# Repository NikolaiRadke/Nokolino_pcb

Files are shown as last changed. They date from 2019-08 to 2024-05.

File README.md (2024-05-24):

Nokolino  

The ATtiny-based litte brother of Noko. Tiny and cute. And everyone is invited to **contribute**. Nokolino is for everyone. This repository is for the **PCB** version of Nokolino, easy and fast to build. See [PCB](https://github.com/NikolaiRadke/NOKOlino_2/tree/master/PCB.md) on how to get your own boards. Do you own a complete kit? Look [here](https://github.com/NikolaiRadke/Nokolino).    
  
What's new? See the [newsblog](https://github.com/NikolaiRadke/NOKOlino_2/tree/master/NEWS.md).   

Three NOKOlinos
  
Like his big brother **Noko**, the little Nokolino delights it's surroundings with cheeky comments. But unlike Noko he is more obstinate - no radio, a display, no frills. Instead of an Arduino he has a small **ATtiny** microcontroller, only an on-off switch and a big button. But he is small, can stay active for days and is, in contrast to his big brother, very easy to build.  
  
Another useful application option would be to use the hardware without the monster suit as a **music box** in an old used doll to bring it back to modern days, maybe with other sounds or songs.  

What does he to - technically? Whenever you press his button, he will laugh. And when he's just turned on, he says something random randomly every statistically 10 minutes. That's ist. Quiet a lot for a stuffed monster!  
  
**Nokolino** stands for **No**ra and Ni**ko**s monster - the appendix **lino** describes the small version.  
  
### Notes for non-German Nokolino makers  
  
Right now, the building wiki, the voice set and the manual are in German. I'll try to translate the wiki and the manual one day. Until then, feel free to ask me for translation, if you need help. **Contribute!** I need an English voice set and English text files. In addition, any other language is welcome, Nokolino is to be cosmopolitan!
  
### Prerequisites
  
Nokolino needs Arduino IDE 1.6.6 or newer (https://www.arduino.cc/en/Main/Software). Copy the folder `Nokolino/src/Nokolino_V30/` for the **JQ6500** module, `Nokolino/src//Nokolino_V31/` for the **JQ8400** module, `Nokolino/src/Nokolino_V32/`for the **DFPlayer** module or `Nokolino/src/Nokolino_V21/` for **older 2018 kits** into your sketch folder and install ATtiny support. See [how to compile](https://github.com/NikolaiRadke/Nokolino_pcb/tree/master/howto_compile) for further instructions. 
  
### Content

```
Nokolino/
├── howto_compile/
|   Manual how compile the sketches in your Arduino IDE.
|
├── linux_uploader/
|   Tool for uploading MP3-files to the JQ6500.
|
├── manual/
|   Nokolino manuals in PDF format.
|
├── mp3/
|   Voice sets for 32MBit- & 16MBit modules in German. English needed? Contribute!
|   ├── Nokolino/
|   |   Male voice sets, spoken by Carsten Caniglia.
|   |   ├── 2MB/
|   |   |   80 files for smaller (16 MBit) modules.
|   |   └── 4MB/
|   |       164 files for recommended (32 MBit) modules.
|   └── Nokolina/
|       Female voice set, spoken by Norma Anthes
|       ├── 2MB/
|       |   80 files for smaller (16 MBit) modules.
|       └── 4MB/
|           164 files for recommended (32 MBit) modules.
|
├── schematics/
|   The circuit diagrams, 3D cab model and sewing pattern.  
|   └── gerber/
|       The gerber files for the PCB to build by your own.
|       ├── V30/
|       |   The gerbers for the JQ6500 module.
|       ├── V31/
|       |   The gerbers for the JQ8400 module.
|       └── V32/
|           The gerbers for the DFPlayer module.
|
└── src/
    ATtiny sketches
    ├── Nokolino_V21/
    |   Old software for old 2018 kits.
    ├── Nokolino_V30/
    |   The sketch for the JQ6500 module.
    ├── Nokolino_V31/
    |   The sketch for the JQ8400 module.
    └── Nokolino_V32/
        The sketch for the DFPlayer module.
```
### Let's get started!

Interested in Nokolino? Great! Let's start here: [German wiki](https://github.com/NikolaiRadke/Nokolino_pcb/wiki).  
English wiki will follow. One day...

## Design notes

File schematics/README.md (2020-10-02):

# Schematics

* **Nokolino_V32.pdf** Nokolnio's circuit diagram for the DFPlayer module.
* **Nokolino_V31.pdf** Nokolino's circuit diagram for the JQ8400 module.  
* **Nokolino_V30.pdf** Nokolino's circuit diagram for the JQ6500 module.  
* **M2_button_cab.stl** The 3D model for the button cabs for self printing.  
* **Nokolino_Pattern.pdf** Nokolino's sewing pattern.  
* **/gerber**  The folder for the gerber files needed to print your own PCBs.

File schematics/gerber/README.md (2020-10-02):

# Gerber files  
  
Here you find the folders for the gerber files to print the PCBs by a manufactor of your choice. 

**V3.2** is for the DFPlayer module.  
**V3.1** is for the JQ8400 module.  
**V3.0** is for the JQ6500 module.

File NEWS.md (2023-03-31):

# Newsblog
  
# 2023  
* **31.03.2023** Added a deep sleep mode for V3.2. If you forget to turn him off, he will draw only 6,5mAh insted of 16,5mAh.  
* **18.03.2023** Fixed a bug that prevented resetting the battery low flag. Updated all Firmwares to **X.X-180323**. 
* **11.01.2023** Finally i found out that not all DFPlayer devices support USB. Luckilyy new Version 220920 of the MH2024K-24SS chipset solves this nasty issue.  
  
# 2022
* **30.01.2022** Started german wiki integration of the new V3.2 version. Hopefully the last (and best) version for a longer time...  
* **27.01.2022** Firmware **3.2-270122**: All DFPlayer modules are supported now. Battery warning is working reliable and the music box mode can now skip to the next track by pressing the button for 3 seconds. Ready to release.  

# 2021
  
* **17.01.2020** Happy new year" Stay tuned for a complete V3.2 wiki integration.  

# 2020  
  
* **30.09.2020** Firmware **3.2-300920** and V3.2 schematics are online.  
* **29.09.2020** Good news: A new Version **V3.2** with the **DFPlayer** MP3 module for microSD cards is available! Nokolino can be used as a speech set monster and, by pressing the button on startup, as a music box for tons of files, uploadable via USB.  
* **28.08.2020** All Boards are getting a slight rework with JST plugs an cables for easier assembly.
* **10.07.2020** Tested new IDE 1.8.13. Works good.  
* **27.06.2020** Added software support for old V2.1 kits.  
* **25.06.2020** New firmware **3.1-250620**: Music box mode now plays more than one file. 3.0 will follow soon.     
* **23.06.2020** The kit and the workshop ticket are now availabe at [heise shop!](https://maker-faire.de/workshops/bauset-workshops/) Cheers!  
* **12.06.2020** Linked [PCB.md](https://github.com/NikolaiRadke/Nokolino_pcb/blob/master/PCB.md) to my [Aisler](https://aisler.net/Monstermaker) repository for easy pcb ordering.  
* **10.06.2020** A kit is available! Look [here](https://maker-faire.de/workshops/bauset-workshops/).  
* **06.06.2020** New release **V3.0-180520**.  
* **04.06.2020** Updated to firmware **3.0-180520** and **3.1-180520**. Only cleanup changes made.    
* **03.06.2020** Started reworking this repository and the wiki.  
* **02.06.2020** The Nokolino kit and the new repository are ready!    
* **26.03.2020** Finally, i found the last missing part for the new Nokolino kit: A solderless USB plug! The wiki will be updated very soon.   
* **22.03.2020** The V3.1 boards for the JQ8400 modules are working.  
* **09.03.2020** New PCBs arrived! The top board fits perfectly to the new designed M2 screw button caps. The V3.1 with alternative JQ8400 module will be tested soon.  
* **08.03.2020** Tested IDE 1.8.12. Yeah, working.  
* **14.02.2020** Nokolino doesn't need glue anymore! You can 3D print your own M2 button caps and connect the new upper PCB with the four buttons by a M2 6mm screw. Surely, old glue cabs are still working.      
* **13.02.2020** Testet IDE 1.8.11. Again, it's working.  
* **11.02.2020**:
  * New firmware **3.1-110220**: Optimized operating voltage range for new JQ8400.  
  * New firmware **3.0-110220**: Reduced flash size and fixed missing optional startup beep.  
* **10.02.2020** Good news: Bigger JQ6500 modules with 32MBit are getting rare. I made an alternative Version V3.1 for the cheap and easy to buy **JQ8400-10p** module with 32MBit too. The software is working and the new PCBs are ordered. Stay tuned!
* **24.01.2020** New V3.0 PCBs are working great. New instructions and the new German wiki will follow next month.  
* **03.01.2020** New firmware **3.0-030120**. Autodetecting playmode and reduced flash size. Remember, this version will only run on coming PCBs.  
* **01.01.2020** Happy new year! The new V3.0 PCB-files are online. The wiki will be updated after testing was done.  

# 2019
  
* **30.12.2019** New Nokolino V3.0 is comming early next year!   
* **26.09.2019** Tested IDE 1.8.10. Still working.  
* **27.08.2019** New linux upload and repair tool. The make command now works with Debian/Ubuntu/Mint.  
* **05.08.2019** New release **V2.1-030819**.  
* **03.08.2019** Firmware **2.1-030819**: With some small hardware additions Nokolino can get a new voice set via USB!  
* **16.06.2019** Firmware **2.0-160419**: Fixed a bug for the optional dark mode.  
* **14.04.2019** Testet IDE 1.8.9. Works too.  
* **15.01.2019** Firmware **2.0-150119**: Reworked volume control. Some modules have issues after sleep mode.  
* **15.01.2019** Testet IDE 1.8.8. Works well.  

## 2018

* **19.10.2018** New Linux upload tool. You can upload an english interface by typing ./jq6500 -X   
* **26.09.2018** See Nokolino and me at Wissensnacht Ruhr Gelsenkirchen: 28.08.2018.  
* **25.09.2018** Firmware **2.0-250918**: Optional complaining when button is pressed while it is dark.
* **22.09.2018** Firmware **2.0-220918**:
  * Optional startup beep.  
  * Optional phototransistor feature.  
  * Improved volume handling, some modules need more startup time.  
* **07.09.2018** New Nokolino with QI wireless charging module and internal power button is ready! Works great!  
* **05.09.2018** Updated PCB design:
  * More room for a USB cable for your JQ6500.    
  * Opportunity to add the new phototransistor feature.  
* **03.09.2018** See Nokolino an me at the Maker Faire Hannover: 15.09.-16.09. HCC Hannover.  
* **31.08.2018** Firmware **1.0-310818**: Optimized PCB battery warning settings.  
* **29.06.2018** Firmware **1.0-290618**: Improved power saving when battery is low.  
* **16.06.2018** Updated the upload tool.  
* **24.05.2018** Firmware **1.0-240518**: New 16MBit voiceset support.  
* **23.05.2018** Better data compression for 16MBit voiceset. You get 10 more files!  
* **22.05.2018** Added 16Mbit module support.  
* **15.05.2018** Updated the upload tool for the JQ6500 mp3 module. Note that it now needs the **-W** parameter to write files.  
* **14.05.2018** See Noko and me at the Maker Faire 2018 in Berlin: 25.10.2018-28.10.2018, FEZ!  
* **12.05.2018** The new repository for PCB Nokolino is ready! Go on, Nokolino lovers!

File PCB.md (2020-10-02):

# PCB - How to get your own NOKOlino boards

**30.09.2020**  

Nokolino_pcb is made of **two** boards. Both of them are 6x5 cm, with two layers: The **main board** for the buttons, 
the charging module, the ATtiny and the MP3 module, the **top board** for the speaker. The battery is on the 
downside of the main board.  

There are three versions: **V3.0** for the **JQ6500-16p** MP3 module, **V3.1** for the **JQ8400-10p** MP3 module and **V3.2** for the **DFPlayer**. I recommend using the newer JQ8400, if you just need a monster. Do you want Nokolino to play longer files like musc then choose the DFPlayer.  
  
There are **three** ways to get your own set of boards:

1. Upload the chosen [gerber files](https://github.com/NikolaiRadke/Nokolino_pcb/tree/master/schematics/gerber) to a PCB manufactor of your choice. In China, you can order a set of 10 boards for about 15€ in less then three weeks. If you are in a hurry, you can choose express shipping. But be careful: in Germany, if your order has a value more than 22€ including shipping costs, you have to pay taxes and a processing fee, which also takes additional time! So try to keep your or order **below 22€**! if you need help, feel free to contact me. Order specifications: two layers and standard presets like PCB thickness 1.6. In Germany, i recommend [Aisler](https://aisler.net/Monstermaker), were you get three PCBs for less then 19€, including shipment. With the top PCB, 38€ for three Nokolinos within three days. Fair.    
 
2. There will be a complete kit available in the heise store. Look at the [kit repository](https://github.com/NikolaiRadke/Nokolino) and stay tuned!  
  
3. Contact me. I have always some boards and sometimes a few kits left. But please: First try to order them by yourself as written in option 1.

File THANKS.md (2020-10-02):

# Thanks

These people helped me bringing life to Nokolino:  
  
- **Hans Radke** - (my dad) hardware construction and a lot of soldering.
- **Regina Radke** - (my mom) monster suit hints.  
- **Nora Linder** - creating and sewing the monster suit and spellchecking.
- **Carsten Caniglia** - the male voice of Nokolino. Look at his [Homepage](http://www.carstencaniglia.com).  
- **Norma Anthes** - the female voice of Nokolino or Nokolina. Look hat her [Homepage](http://norma-anthes.de).  
- **Helga Hansen** - from the Make Magazin for promoting Nokolino.  
- **Thomas Stolt** - PCB design and bugfixes.  
- **Jan Fanslau** - PCB rework and beer. Look at his [Projects](https://janfanslau.com).  
- **Elisabeth Seidl** - Media design.  
  
Active supporters:  

- **"Brickhub"** - bugfixes.  
- **Horst Friedrich** - the phototransistor idea.  
- **Daniel Bachfeld** - the QI wireless charging idea.  
- **"Nickneck"** - translating the JQ6500 uploader.  
- **Reinhard Max** - for the upload and rescue tool.  
  
Used ressources:  

- **Arduino board and IDE** - [www.arduino.cc](http://www.arduino.cc)  
- **ATtiny core** - [David A. Mellis](https://github.com/damellis)  
- **JQ6500 uploader** - [Reinhard Max](http://chiselapp.com/user/rmax/repository/jq6500)  
- **Suit inspiration - Ninni** - [RevoluzZa Blog](http://blog.revoluzzza.com/2009/02/25/tutorial-hopw-to-sew-a-revoluzzzionary-monster-wie-man-ein-revoluzzzionares-monster-naht/)  
- **VCC measuring** - [Tim on mikrocontroller.net](https://www.mikrocontroller.net/topic/315667)

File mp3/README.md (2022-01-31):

# Voice set for Nokolino - German

Here you find four voice sets: Nokolino for the male and Nokolina for the female version, each with **2MB** for **16 MBit JQ6500** modules and **4MB** for the **32 MBit JQ6500, JQ8400 and DFPlayer** modules.  

## DFPlayer
  
Plug in your DFPlayer module or Nokolino and put the voice set in folder **01** on your SD card. In folder **02** you can put your own mp3 files for the music box mode, named 001.mp3 to 999.mp3.   

## JQ8400  
  
Plug in your JQ8400 module or Nokolino, delete the old files and copy the new mp3s on the module. Strictly observe the sequence! 021.mp3 must be copied as the 21st file. See the Wiki for more detailed instructions.

Linux and Mac can copy the files by simply marking them all and draging them into the folder. Windows has it's issues with the copying sequence. You can either copy them one by one oder use a copy tool like SmartCopyTool.

## JQ6500
  
**Windows** users can use the (chinese) interface. See this [instructions](http://sparks.gogo.co.nz/jq6500/index.html), written by James Sleeman. if you want an English interface or is the interface missing, look at my [JQ6500 rescue tool](https://github.com/NikolaiRadke/JQ6500-rescue-tool).  
  
**Linux** and **Mac** users should try the [uploading tool](https://github.com/NikolaiRadke/Nokolino_pcb/tree/master/linux_uploader), written by Max Reinhard.  

## Voice set structure  
  
**4MB**  

| Number  | Assignment |
| ---|---:|
| 001-040 | Response to belly button |
| 041-163 | Time based events |
| 164 | BEEP battery warning |
  
**2MB**  

| Number  | Assignment |
| ---|---:|
| 001-030 | Response to belly button |
| 031-079 | Time based events |
| 080 | BEEP battery warning |
  
The male voice has been spoken by my fellow actor [Carsten Caniglia](https://filmmakers.de/carsten-caniglia). Why? 
He has done a great job - moreover I don't want to listen to my own voice every day, especially when development takes more than a year! (Ian said I sound really weird in real life. Thanks, mate.). The female voice was spoken by my fellow actress [Norma Anthes](http://norma-anthes.de). Thank you, lady!    

### Your own voice set  
  
You want to use your own files? No problem. Look into the sketch **Nokolino.ino**. Change the lines  
``` #define Button_event  0 ```  for the last voice file when the button is pressed and  
``` #define Time_event   0``` for the last voice file for the time based events.  
The *beep* for the battery warning should be the last file.  
In **V3.0** set the definition **Set_own**. The **JQ6500** allows up to **65536** files, if the fit into the flash memory. The **JQ8400** is due programing issues limited to **255** files. That seems to be still enough.  
  
Keep in your mind, that the **JQ6500** memory is limited to **4Mbyte - 256kb** or **2Mbyte - 256kb**! The **JQ8400** provides full **4Mbyte**.

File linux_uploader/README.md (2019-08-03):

# Uploading files on the JQ6500 with Linux

It is quite easy with this command line tool, written by [Reinhard Max](https://chiselapp.com/user/rmax/repository/jq6500).  I added a precompiled version (64 Bit). It is free, but it is also *beerware*... ;-)  

1. Check, if ``` ./jq6500 ``` is running.  
2. If not, compile it by yourself, just by typing ``` make ```. 
3. Try again.
4. Connect your JQ6500 module to your system with a micro USB cable. 
5. Test your device by typing  ``` ./jq6500 -S ```. The tool will tell you the detected flash size.  
6. 32 MBit modules: Upload your files by typing ``` ./jq6500 -W ../mp3/male/mp3_32MBit/* ```(32 MBit male voice)  or ``` ./jq6500 -W ../mp3/female/mp3_32MBit/* ``` (32 MBit female voice).  
7. 16 MBit modules: Upload your files by typing ``` ./jq6500 -W ../mp3/male/mp3_16_MBit/* ```(16 MBit male voice)  or ``` ./jq6500 -W ../mp3/female/mp3_16MBit/* ``` (16 MBit female voice). 

If your MP3 files are in another directory, modify the last argument.  

## Repairing a JQ6500 without Windows software with Linux
  
Strangely, some modules come without the integrated Windows software. If you have a friend in need without Linux, the tool can fix the module.

1. Like above, check if the tool is running correctly.  
2. Connect your JQ6500 module to your system with a micro USB cable.  
3. Just type ``` ./jq6500 -X ```. 

That's it. You can now use your module with Windows.  

## Repairing a JQ6500 without Windows software without Linux
  
If you are a Windows user see my [JQ6500-rescue-tool](https://github.com/NikolaiRadke/JQ6500-rescue-tool) repository. There you find a quite simple way to fix your module.

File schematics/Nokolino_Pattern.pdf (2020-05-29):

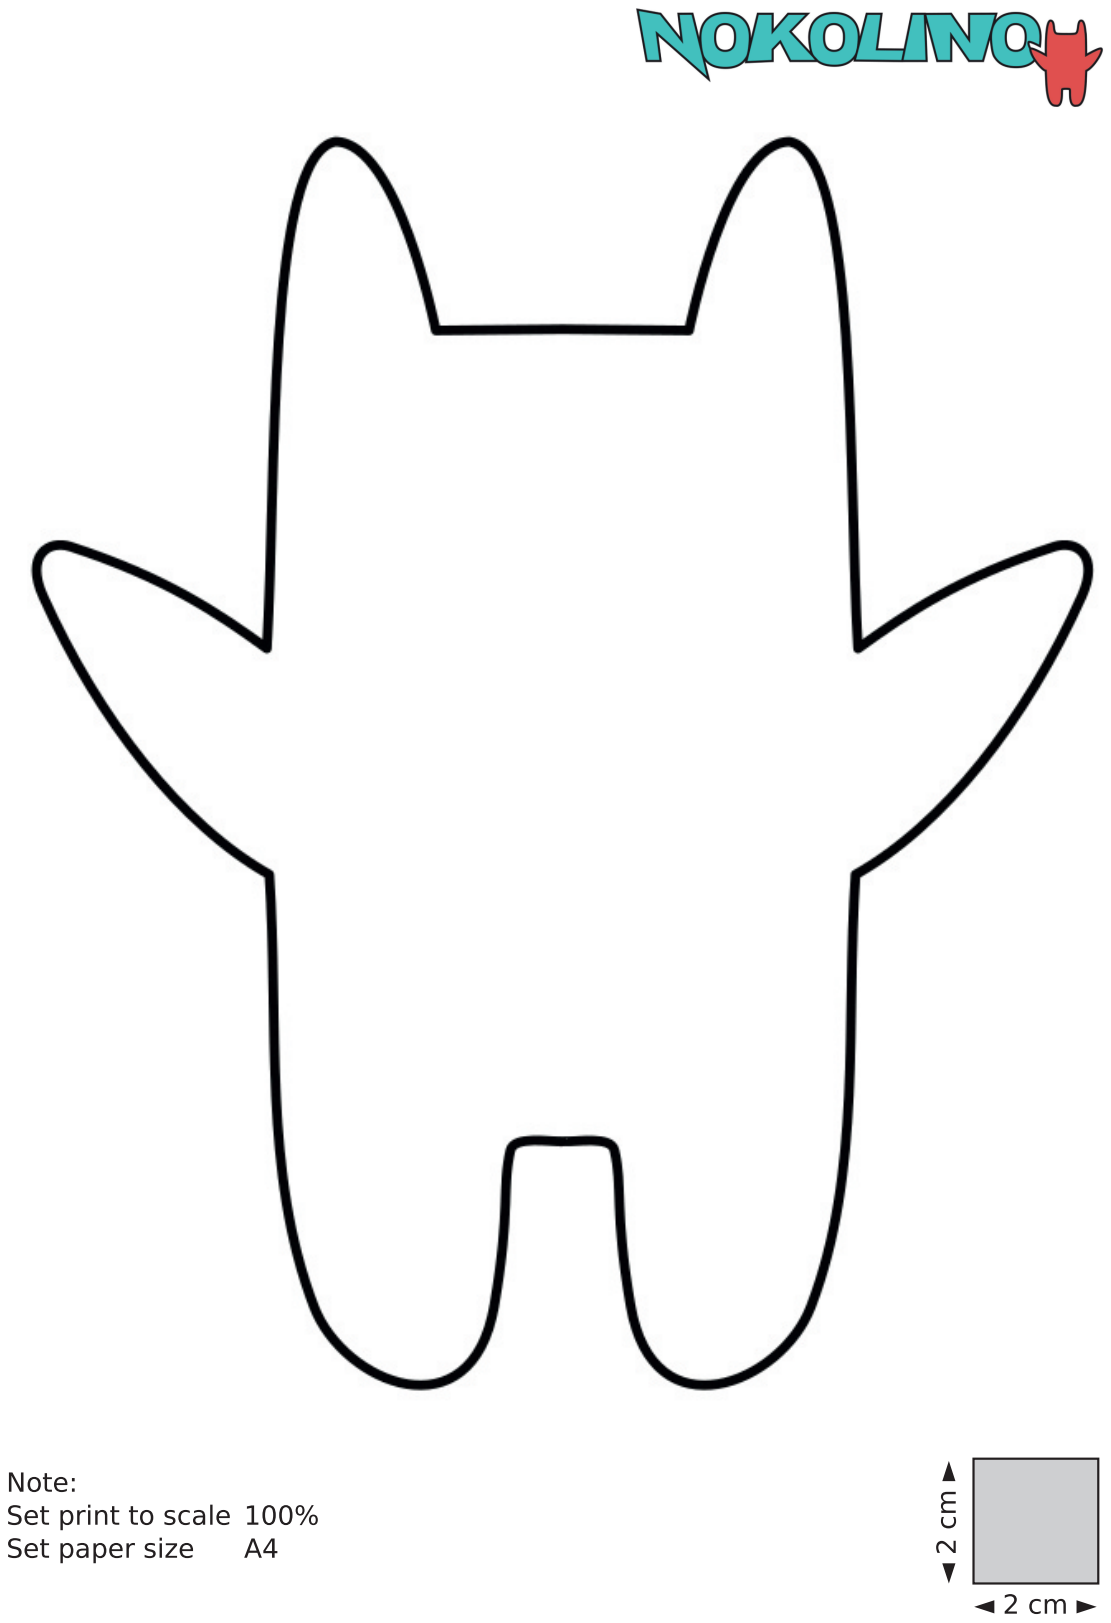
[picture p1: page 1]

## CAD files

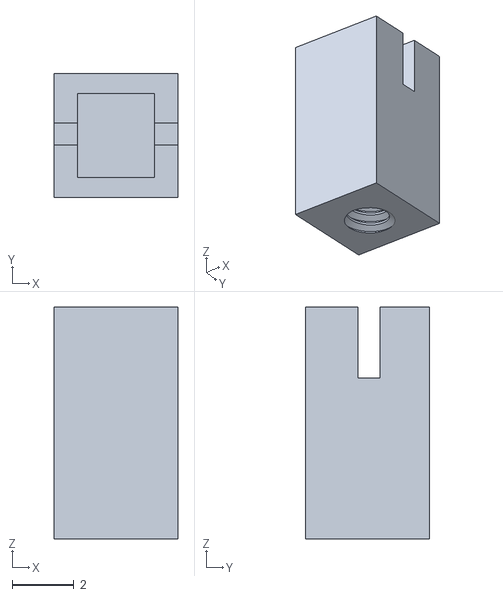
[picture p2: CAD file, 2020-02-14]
schematics/M2_button_cab.stl
4.00 x 4.00 x 7.50

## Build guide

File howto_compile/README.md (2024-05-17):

# Compiling instructions for Nokolino

In order to flash your ATtiny with the Nokolino-sketch, you need the **Arduino-IDE** (1.6.6 or higher), with installed **ATtiny support** and an **Arduino** connected to your microcontroller.

### Preparing the IDE  
 
1. Open ``` File > Preferences ```.  
2. Find the field ``` Additional Boards Manager URLs ```.  
3. Enter ``` https://raw.githubusercontent.com/damellis/attiny/ide-1.6.x-boards-manager/package_damellis_attiny_index.json ```.  
4. Press ``` OK ```.  
5. Open ``` Tools > Board > Boards Manager ```.  
6. Select ``` attiny by David A. Mellis ```.  
7. Press ``` Install ```.

### Peparing your Arduino  

1. Connect your Arduino to your system.  
2. Open ``` File > Examples > ArduinoISP > ArduinoISP ```.  
3. Upload the sketch.

### Connecting your ATtiny with the Arduino  

1. Disconnect your Arduino.
2. Connect your ATtiny as seen below.
3. Add the 10uF capacitor.    
   
ATTINY-ARDUINO  
  
### Burning an ATtiny bootloader  

1. Connect your Arduino to your system again.  
2. Select ``` Tools > Programmer > Arduino as ISP ```.  
3. Select ``` Tools > Board > ATtiny25/45/85 ```.  
4. Select ``` Tools > Processor > ATtiny85 ``` or ``` Tools > Processor > ATtiny45 ```.  
5. Select ``` Tools > Clock > 8 MHz (internal) ```.  
6. Start burning process with ``` Tools > Burn Bootloader ```.  

Now you can flash your ATtiny with any sketch you want! But this time, we focus on Nokolino.  

### Configuring Nokolino.ino

For **V3.2**, **V3.1** and **V3.0** versions. If you need **V2.1** for an old kit, everything is preset.  

1. Set the avarage talking interval in line 31 (10 for 10 minutes is preset).  
2. Set the volume in line 32. 25 is recommended for Nokolino, 22 for Nokolina.  
3. Are you building Nokolino on a breadboard? Set line 35.  
4. Select your voice set in line 38, 39 or 40  
5. If you don't want any battery warnings, comment out line 64.  
6. If you want Nokolino to be quiet on startup, comment out line 67.  
7. Check line 65 and 66 if you are using the optional light sensor.  

### Flashing Nokolino firmware
  
1. Open sketch **Nokolino.ino**.  
2. Select ``` Sketch > Upload with programmer ``` to flash the firmware.  
3. DONE.  

Now you can remove the microcontroller. You should keep the wireing alive to easly make some changes in the firmware.  

### Hints for Linux users
With some Debain-based distributions like Ubuntu or Mint you might recieve an error while trying to upload your sketch to the ATtiny like  
``` avrdude: ser_open(): can't open device "/dev/ttyUSB0": Permission denied. ```  
This issue can be solved by adding your user to the dialout-group. Open a terminal and type  
``` sudo usermod -a -G dialout $USERNAME ```.  
Enter your password and restart. Now it should work.

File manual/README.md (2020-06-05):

# Manual for Nokolino  
  
This folder contains the four page manuals V30 and V31 as a PDF, written in German. The other files are intended for printing a smaller manual with two pages on one. Choose duplex and long edge.

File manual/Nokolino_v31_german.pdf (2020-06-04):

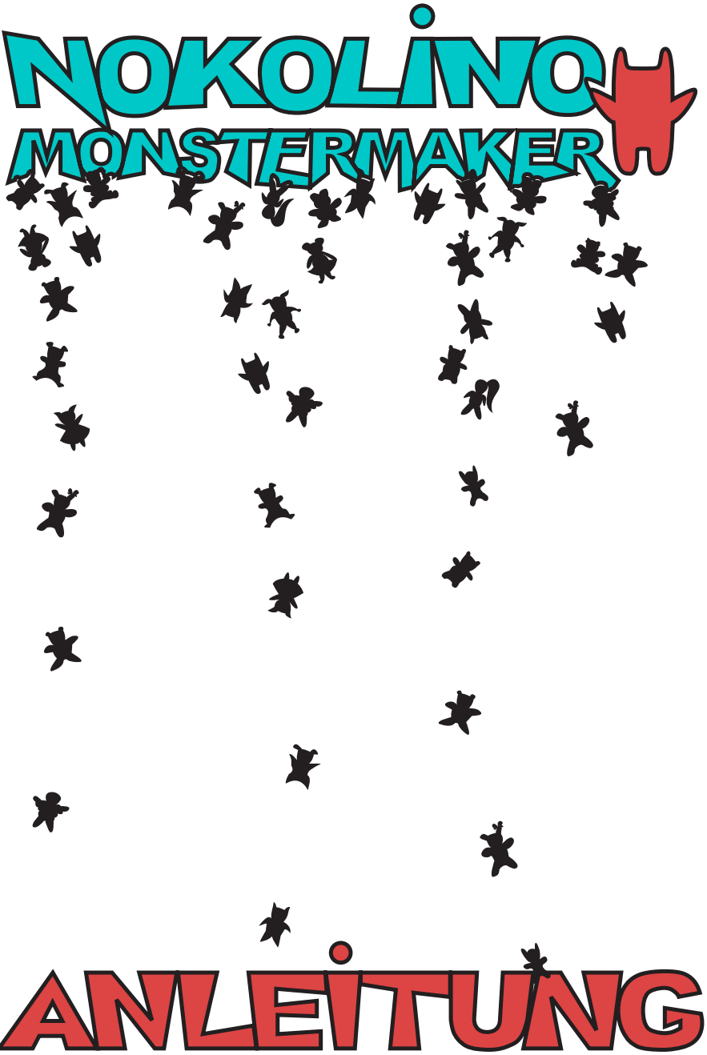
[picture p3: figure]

## Sprachset aufspielen

Als würde man das Gehirn tauschen: Einfach Nokolino an einen Computer über den USB- Port anschließen, Nokolino einschalten und schon kann das Sprachset getauscht werden. Wie bei einem USB-Stick werden die Dateien angezeigt. Einfach alle löschen und die neuen 164 MP3-Dateien auf Nokolino kopieren. Wichtig ist dabei nur, die Reihenfolge einzuhalten, also zuerst 001.mp3 kopieren, dann 002.mp3 usw.
Nun ja, ganz so einfach ist es dann doch nicht. Mit einem Mac und bei Linux klappt das problemlos. Einfach alle Dateien markieren und in das Verzeichnis schieben. Leider hat Windows jedoch ganz eigene Vorstellungen von einer Kopierreihenfolge, was das Sprachset durcheinander bringt. Entweder müssen alle 164 Dateien einzeln kopiert oder ein Kopierprogramm verwendet werden, z.B. Smartcopytool. (https://sourceforge.net/projects/smartcopytool) Nach dem Kopieren wird Nokolino ausgeschaltet und vom Computer getrennt. Danach wieder einschalten und schon ist er eine sie oder sie ein er oder er ein es oder was auch immer beliebt.

## Hinweise

Nokolino ist mit Schutzschaltungen ausgestattet.
Dennoch sollte zur Akkuschonung Nokolino nicht mit leerem Akku gelagert werden. Ladespannung: 5V 1A
Akku: LiPo 3,7V mit Überhitzungs- und Entladeschutz

## Fragen bitte an

kontakt@nikolairadke.de
Nokolino wurde entworfen, programmiert und gebaut von Niko, genäht hat ihn Nora.

## Danke an

Nikos Vater (Bau und Test), Carsten Caniglia (Nokolinos Stimme)
und Norma Anthes (Nokolinas Stimme).

## Interesse an Nokolino?

www.monstermaker.de

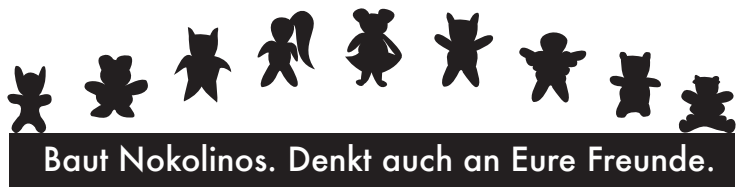
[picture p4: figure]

Baut Nokolinos. Denkt auch an Eure Freunde.

## Nokolino zum Anfassen

### Nokolino hat unter seinem monströsen Fell ein paar verborgene Stellen:

## Einführung

Nokolino ist zuhause, der kleine Bruder von Noko. Der kleine freche Bruder von Noko. Nein, der kleine noch frechere Bruder von Noko. Denn während Noko noch Musik spielen und seinen Besitzer wecken kann, ein Licht in der Nacht bietet und immer die Uhrzeit weiß, ist Nokolino nur frech. Aber er ist ja noch so klein und kann das, was sein großer Bruder alles kann, noch nicht. Dafür ist er niedlich, klein und ein witziger Begleiter. Noko steht für Noras und Nikos Monster. Nokolino ist also ein kleiner Noko. Soll es lieber eine Nokolina oder jemand ganz anderes sein? Kein Problem, das Sprach-

set lässt sich jederzeit wechseln.

## Was kann Nokolino?

### Wenn rumsitzen und ab und an einen Kommentar von sich geben ein Können ist, so kann Nokolino das wirklich gut. Ebenso kommentiert er es, wenn sein Bauch gedrückt wird, er ist nämlich schrecklich kitzelig. Über zwei Tage lang unterhält er seine Mitmenschen und Mitmonster, bevor er wieder zum

Füttern an die Steckdose muss. Und das Beste: Man kann ihn ausschalten, sofern man nicht gerne nachts geweckt werden will.

### Was kann man also mit ihm machen?

Nun, was kann man mit einem Hamster machen? Gerne haben. Anfassen.

### Knuddeln. Mitnehmen. Freunden zeigen. Mitmenschen ärgern und Nokolino unter das Bett legen, denn ein anständiges Monster mag Faxen!

## Wozu diese Anleitung?

### Monster brauchen Pflege. Nokolino ist recht anspruchslos, aber ein bisschen

Zuwendung muss sein Besitzer schon aufbringen. Das wird hier erklärt.

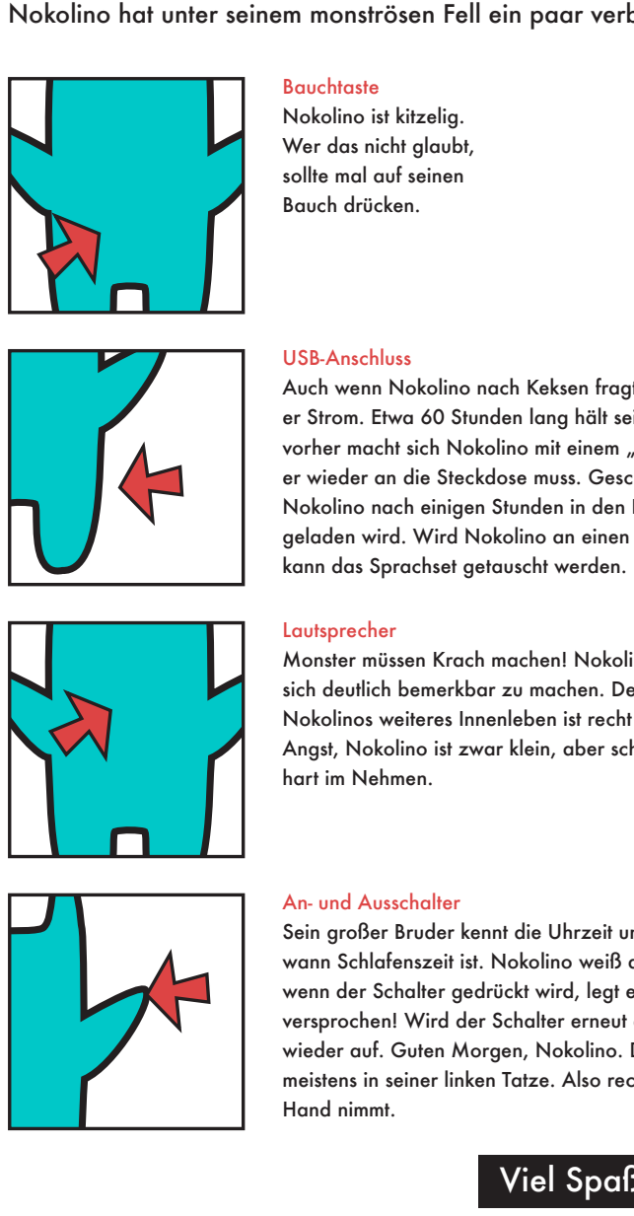
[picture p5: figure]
Bauchtaste Nokolino ist kitzelig. Wer das nicht glaubt, sollte mal auf seinen Bauch drücken.; USB-Anschluss; kann das Sprachset getauscht werden.; Lautsprecher; hart im Nehmen.; An- und Ausschalter; Hand nimmt.

Auch wenn Nokolino nach Keksen fragt: Am nötigsten braucht er Strom. Etwa 60 Stunden lang hält sein Akku. Einige Stunden vorher macht sich Nokolino mit einem „PIEP“ bemerkbar, wenn er wieder an die Steckdose muss. Geschieht das nicht, so tritt Nokolino nach einigen Stunden in den Hungerstreik, bis er geladen wird. Wird Nokolino an einen Computer angeschlossen,

Monster müssen Krach machen! Nokolino ist laut genug, um sich deutlich bemerkbar zu machen. Der Lautsprecher und Nokolinos weiteres Innenleben ist recht gut geschützt. Keine Angst, Nokolino ist zwar klein, aber schon ein ganzer Kerl und

Sein großer Bruder kennt die Uhrzeit und weiß ziemlich genau, wann Schlafenszeit ist. Nokolino weiß das leider nicht, aber wenn der Schalter gedrückt wird, legt er sich sofort schlafen, versprochen! Wird der Schalter erneut gedrückt, wacht er wieder auf. Guten Morgen, Nokolino. Der Schalter befindet sich meistens in seiner linken Tatze. Also rechts, wenn man ihn in die

## Viel Spaß mit Nokolino!

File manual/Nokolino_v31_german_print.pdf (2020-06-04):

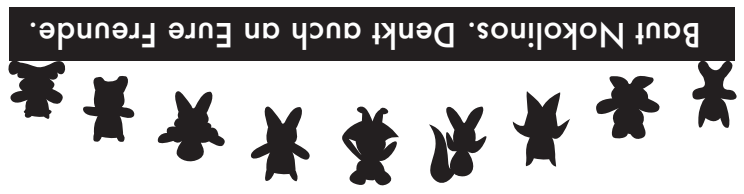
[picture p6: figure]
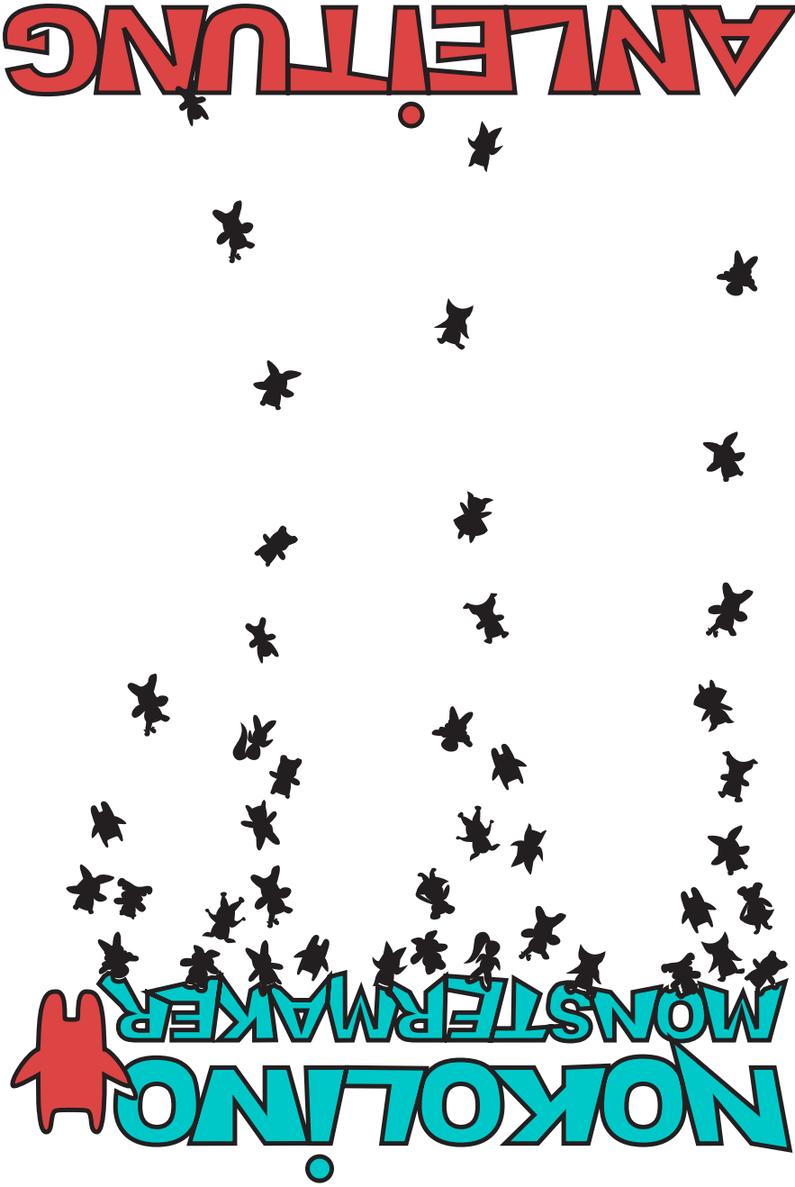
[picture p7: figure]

## Sprachset aufspielen

Als würde man das Gehirn tauschen: Einfach Nokolino an einen Computer über den USB- Port anschließen, Nokolino einschalten und schon kann das Sprachset getauscht werden. Wie bei einem USB-Stick werden die Dateien angezeigt. Einfach alle löschen und die neuen 164 MP3-

Dateien auf Nokolino kopieren. Wichtig ist dabei nur, die Reihenfolge einzuhalten, also zuerst

001.mp3 kopieren, dann 002.mp3 usw.

- Nun ja, ganz so einfach ist es dann doch nicht. Mit einem Mac und bei Linux klappt das prob lemlos. Einfach alle Dateien markieren und in das Verzeichnis schieben. Leider hat Windows
- jedoch ganz eigene Vorstellungen von einer Kopierreihenfolge, was das Sprachset durchein ander bringt. Entweder müssen alle 164 Dateien einzeln kopiert oder ein Kopierprogramm verwendet werden, z.B. Smartcopytool. (https://sourceforge.net/projects/smartcopytool)

Nach dem Kopieren wird Nokolino ausgeschaltet und vom Computer getrennt. Danach wieder einschalten und schon ist er eine sie oder sie ein er oder er ein es oder was auch immer beliebt.

## Hinweise

Nokolino ist mit Schutzschaltungen ausgestattet.

Dennoch sollte zur Akkuschonung Nokolino nicht mit leerem Akku gelagert werden.

Ladespannung: 5V 1A

Akku: LiPo 3,7V mit Überhitzungs- und Entladeschutz

## Fragen bitte an

kontakt@nikolairadke.de

Nokolino wurde entworfen, programmiert und gebaut von Niko, genäht hat ihn Nora.

## Danke an

Nikos Vater (Bau und Test), Carsten Caniglia (Nokolinos Stimme) und Norma Anthes (Nokolinas Stimme).

## Interesse an Nokolino?

www.monstermaker.de

Baut Nokolinos. Denkt auch an Eure Freunde.

## Nokolino zum Anfassen

### Nokolino hat unter seinem monströsen Fell ein paar verborgene Stellen:

## Einführung

Nokolino ist zuhause, der kleine Bruder von Noko. Der kleine freche Bruder von Noko. Nein, der kleine noch frechere Bruder von Noko. Denn während Noko noch Musik spielen und seinen Besitzer wecken kann, ein Licht in der Nacht bietet und immer die Uhrzeit weiß, ist Nokolino nur frech. Aber er ist ja noch so klein und kann das, was sein großer Bruder alles kann, noch nicht. Dafür ist er niedlich, klein und ein witziger Begleiter. Noko steht für Noras und Nikos Monster. Nokolino ist also ein kleiner Noko. Soll es lieber eine Nokolina oder jemand ganz anderes sein? Kein Problem, das Sprach-

set lässt sich jederzeit wechseln.

## Was kann Nokolino?

### Wenn rumsitzen und ab und an einen Kommentar von sich geben ein Können ist, so kann Nokolino das wirklich gut. Ebenso kommentiert er es, wenn sein Bauch gedrückt wird, er ist nämlich schrecklich kitzelig. Über zwei Tage lang unterhält er seine Mitmenschen und Mitmonster, bevor er wieder zum

Füttern an die Steckdose muss. Und das Beste: Man kann ihn ausschalten, sofern man nicht gerne nachts geweckt werden will.

### Was kann man also mit ihm machen?

Nun, was kann man mit einem Hamster machen? Gerne haben. Anfassen.

### Knuddeln. Mitnehmen. Freunden zeigen. Mitmenschen ärgern und Nokolino unter das Bett legen, denn ein anständiges Monster mag Faxen!

## Wozu diese Anleitung?

### Monster brauchen Pflege. Nokolino ist recht anspruchslos, aber ein bisschen

Zuwendung muss sein Besitzer schon aufbringen. Das wird hier erklärt.

Bauchtaste Nokolino ist kitzelig. Wer das nicht glaubt, sollte mal auf seinen Bauch drücken.; USB-Anschluss; kann das Sprachset getauscht werden.; Lautsprecher; hart im Nehmen.; An- und Ausschalter; Hand nimmt.

Auch wenn Nokolino nach Keksen fragt: Am nötigsten braucht er Strom. Etwa 60 Stunden lang hält sein Akku. Einige Stunden vorher macht sich Nokolino mit einem „PIEP“ bemerkbar, wenn er wieder an die Steckdose muss. Geschieht das nicht, so tritt Nokolino nach einigen Stunden in den Hungerstreik, bis er geladen wird. Wird Nokolino an einen Computer angeschlossen,

Monster müssen Krach machen! Nokolino ist laut genug, um sich deutlich bemerkbar zu machen. Der Lautsprecher und Nokolinos weiteres Innenleben ist recht gut geschützt. Keine Angst, Nokolino ist zwar klein, aber schon ein ganzer Kerl und

Sein großer Bruder kennt die Uhrzeit und weiß ziemlich genau, wann Schlafenszeit ist. Nokolino weiß das leider nicht, aber wenn der Schalter gedrückt wird, legt er sich sofort schlafen, versprochen! Wird der Schalter erneut gedrückt, wacht er wieder auf. Guten Morgen, Nokolino. Der Schalter befindet sich meistens in seiner linken Tatze. Also rechts, wenn man ihn in die

## Viel Spaß mit Nokolino!

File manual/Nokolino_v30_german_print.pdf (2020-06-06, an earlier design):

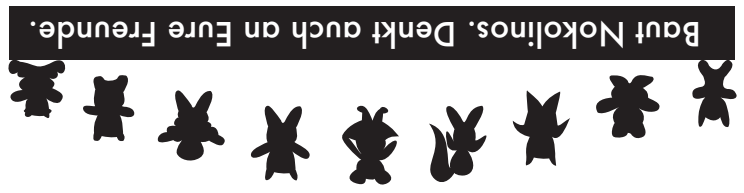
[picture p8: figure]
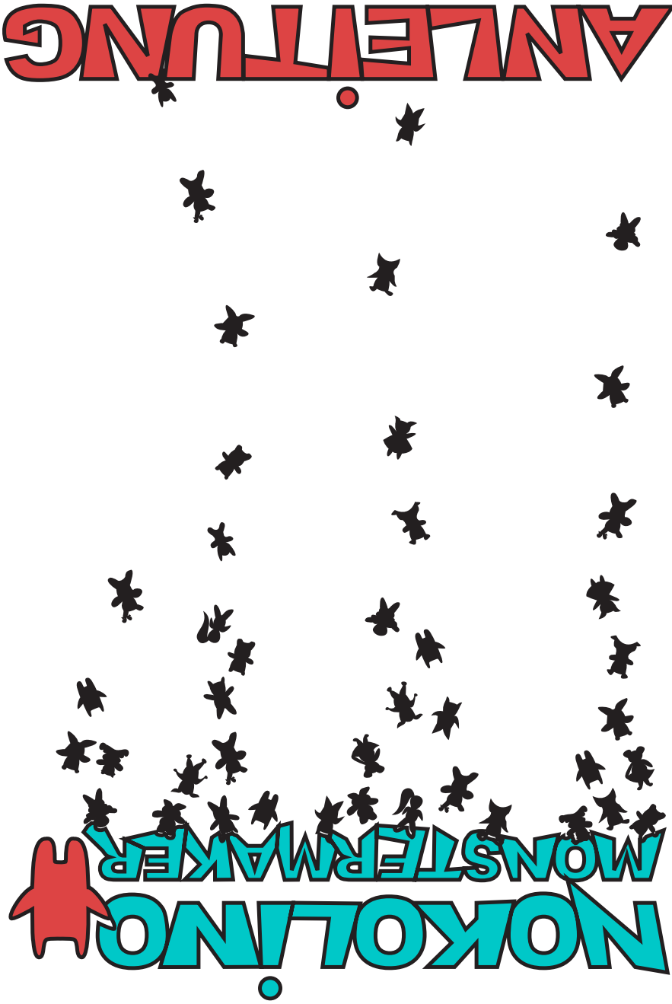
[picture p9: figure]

## Sprachset aufspielen

Als würde man das Gehirn tauschen: Einfach Nokolino an einen Computer über den USB- Port

- anschließen, Nokolino einschalten, dabei die Bauchtaste drücken und schon kann das Sprach

set getauscht werden.

Mehr dazu unter https://github.com/NikolaiRadke/Nokolino_pcb/wiki/MP3s-aufspielen

Nach dem Kopieren wird Nokolino ausgeschaltet und vom Computer getrennt. Danach wieder einschalten und schon ist er eine sie oder sie ein er oder er ein es oder was auch immer beliebt.

## Hinweise

Nokolino ist mit Schutzschaltungen ausgestattet.

Dennoch sollte zur Akkuschonung Nokolino nicht mit leerem Akku gelagert werden.

Ladespannung: 5V 1A

Akku: LiPo 3,7V mit Überhitzungs- und Entladeschutz

## Fragen bitte an

kontakt@nikolairadke.de

Nokolino wurde entworfen, programmiert und gebaut von Niko, genäht hat ihn Nora.

## Danke an

Nikos Vater (Bau und Test), Carsten Caniglia (Nokolinos Stimme) und Norma Anthes (Nokolinas Stimme).

## Interesse an Nokolino?

www.monstermaker.de

Baut Nokolinos. Denkt auch an Eure Freunde.

## Nokolino zum Anfassen

### Nokolino hat unter seinem monströsen Fell ein paar verborgene Stellen:

## Einführung

Nokolino ist zuhause, der kleine Bruder von Noko. Der kleine freche Bruder von Noko. Nein, der kleine noch frechere Bruder von Noko. Denn während Noko noch Musik spielen und seinen Besitzer wecken kann, ein Licht in der Nacht bietet und immer die Uhrzeit weiß, ist Nokolino nur frech. Aber er ist ja noch so klein und kann das, was sein großer Bruder alles kann, noch nicht. Dafür ist er niedlich, klein und ein witziger Begleiter. Noko steht für Noras und Nikos Monster. Nokolino ist also ein kleiner Noko. Soll es lieber eine Nokolina oder jemand ganz anderes sein? Kein Problem, das Sprach-

set lässt sich jederzeit wechseln.

## Was kann Nokolino?

### Wenn rumsitzen und ab und an einen Kommentar von sich geben ein Können ist, so kann Nokolino das wirklich gut. Ebenso kommentiert er es, wenn sein Bauch gedrückt wird, er ist nämlich schrecklich kitzelig. Über zwei Tage lang unterhält er seine Mitmenschen und Mitmonster, bevor er wieder zum

Füttern an die Steckdose muss. Und das Beste: Man kann ihn ausschalten, sofern man nicht gerne nachts geweckt werden will.

### Was kann man also mit ihm machen?

Nun, was kann man mit einem Hamster machen? Gerne haben. Anfassen.

### Knuddeln. Mitnehmen. Freunden zeigen. Mitmenschen ärgern und Nokolino unter das Bett legen, denn ein anständiges Monster mag Faxen!

## Wozu diese Anleitung?

### Monster brauchen Pflege. Nokolino ist recht anspruchslos, aber ein bisschen

Zuwendung muss sein Besitzer schon aufbringen. Das wird hier erklärt.

Bauchtaste Nokolino ist kitzelig. Wer das nicht glaubt, sollte mal auf seinen Bauch drücken.; USB-Anschluss; kann das Sprachset getauscht werden.; Lautsprecher; hart im Nehmen.; An- und Ausschalter; Hand nimmt.

Auch wenn Nokolino nach Keksen fragt: Am nötigsten braucht er Strom. Etwa 60 Stunden lang hält sein Akku. Einige Stunden vorher macht sich Nokolino mit einem „PIEP“ bemerkbar, wenn er wieder an die Steckdose muss. Geschieht das nicht, so tritt Nokolino nach einigen Stunden in den Hungerstreik, bis er geladen wird. Wird Nokolino an einen Computer angeschlossen,

Monster müssen Krach machen! Nokolino ist laut genug, um sich deutlich bemerkbar zu machen. Der Lautsprecher und Nokolinos weiteres Innenleben ist recht gut geschützt. Keine Angst, Nokolino ist zwar klein, aber schon ein ganzer Kerl und

Sein großer Bruder kennt die Uhrzeit und weiß ziemlich genau, wann Schlafenszeit ist. Nokolino weiß das leider nicht, aber wenn der Schalter gedrückt wird, legt er sich sofort schlafen, versprochen! Wird der Schalter erneut gedrückt, wacht er wieder auf. Guten Morgen, Nokolino. Der Schalter befindet sich meistens in seiner linken Tatze. Also rechts, wenn man ihn in die

## Viel Spaß mit Nokolino!

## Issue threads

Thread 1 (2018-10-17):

Kit from Heise

supertobi, 2018-10-17:
I open this question as issue to make it easier to track. Are there any news about the Kit from heise?
In the PCB.md you wrote on 12 May:
"Wait some days longer. The heise Verlag will sell complete NOKOlino kits for an accurate price. Stay tuned for more information."

NikolaiRadke, 2018-10-18:
Good question. Technically, it is ready to be released. I just wrote an email to heise. Last month we agreed to offer the kit early enough before Christmas.

NikolaiRadke, 2018-11-19:
Hello supertobi,

sorry for my late answer. Real life work demanded it's tribute...
Sadly, heise can't release the kit before 2019.

If you need PCBs or Modules, feel free to write me an Email.
kontakt@nikolairadke.de

NikolaiRadke, 2019-04-16:
Alas, they won't sell the kit anymore. I am looking for other ways to sell the kits on my own. Sorry.

Closed 2020-06-12.

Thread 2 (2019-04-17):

gerber: drill map is not matched with drill

Respekt1, 2019-04-17:
Please see attached image. Drill map is not matched with drill file. For pcb production i used the drill file.
Because of missmatching, please regenerate drill map or delete it.

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

NikolaiRadke, 2019-04-17:
Thanks for the hint and sorry fpr the issue. As you suggested, i've removed the ancient drill map.I ordered my PCBs online at www.jlcpcb.com, the drill map has never been an issue there.

Yesterday i ordered another set of an upcoming version. You can now change the speech set via external USB. I haven't recieved the shippment yet, so it is untested. But if you are interested, take a look at directory /schematics/V3 - there you can find the new - drill map-free - gerber files. A new software is required, it is located in src/NOKOlino_3.

When the new PCBs are tested, i will update the repository and wiki.

Closed 2019-08-03.

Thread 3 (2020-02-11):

Gesucht: Neue Tasterkappen mit M2-Gewinde

NikolaiRadke, 2020-02-11:
Leider kommt Nokolino nicht ohne Klebstoff aus. Mit wäre es lieber, wenn die vier Tasterkappen ein kurzes (M2?) Schraubgewinde bekämen, um so die obere Platine anschrauben zu können. Diese Kappen sollen dann weiterhin auf die Tasten geklemmt werden, was sich sich bewährt hat.

Über eine Vorlage zum 3D-Druck würde ich mich sehr freuen! Nachdem die Einarbeit in KiCad schon so viel Zeit gefressen hat, komme ich nicht dazu, mich auch noch mit filigranem 3D-Druck zu befassen.

Liebe Grüße an alle Nokolino-Freunde,

Nikolai

NikolaiRadke, 2020-02-11:
Das sind die bisher verwendeten Kappen:
https://www.reichelt.de/kappe-gelb-quadratisch-4-0-x-4-0-x-5-5-mm-rnd-210-00219-p209514.html?&nbc=1

NikolaiRadke, 2020-02-14:
Fertig. Nokolino kommt jetzt komplett ohne Klebstoff aus.

Closed 2020-02-14.

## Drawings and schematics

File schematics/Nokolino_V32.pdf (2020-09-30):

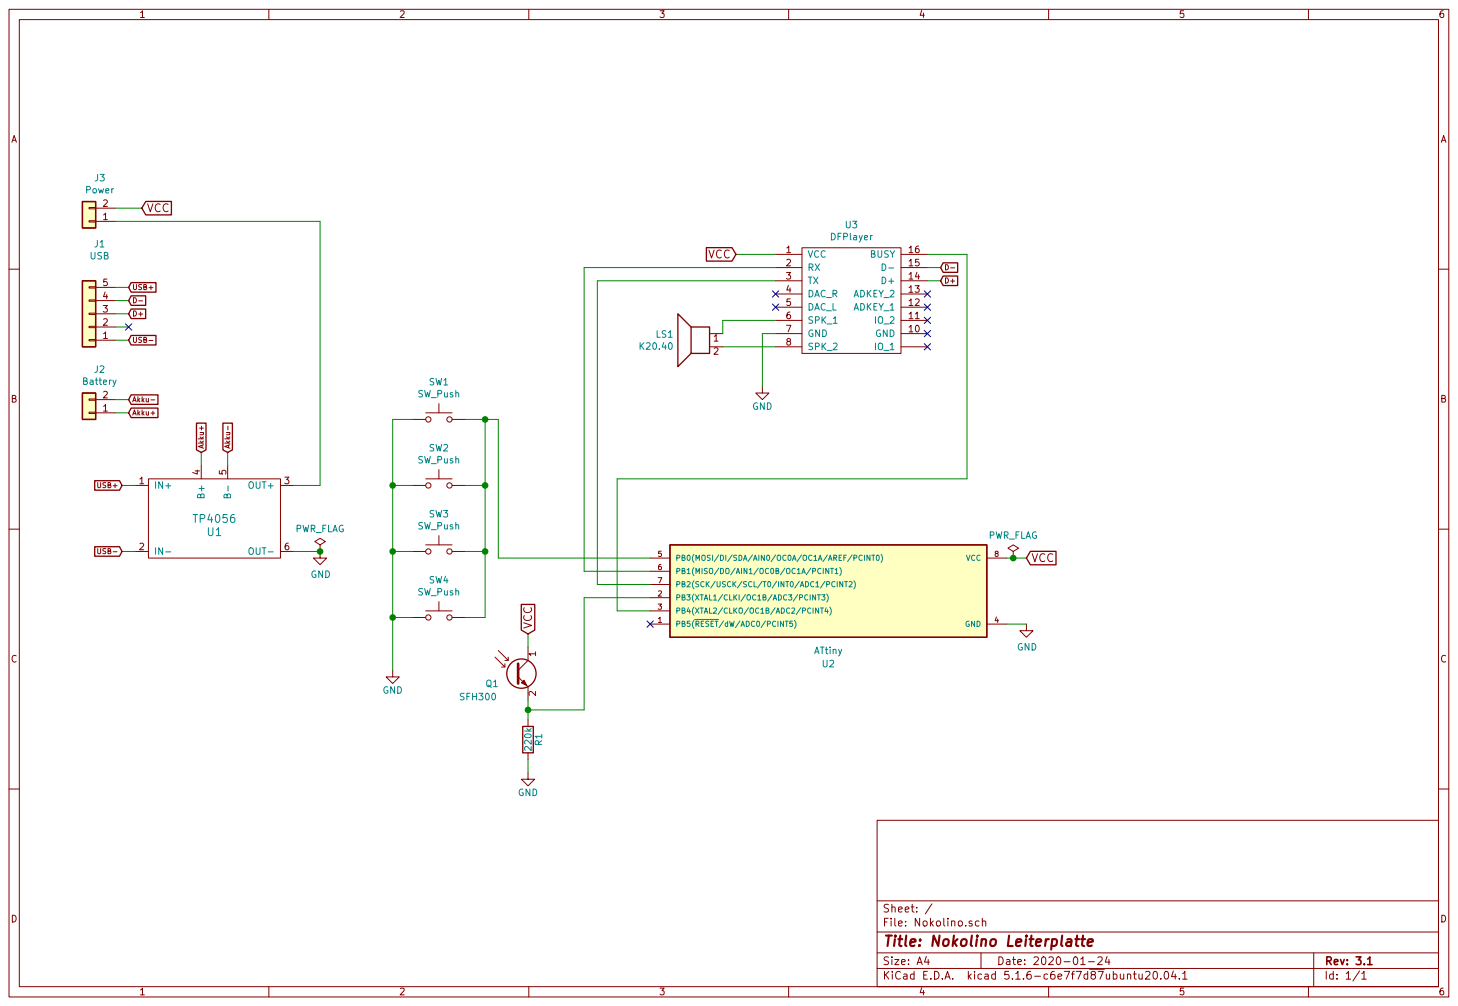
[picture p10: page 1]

Id: 1/1 Title: Nokolino Leiterplatte

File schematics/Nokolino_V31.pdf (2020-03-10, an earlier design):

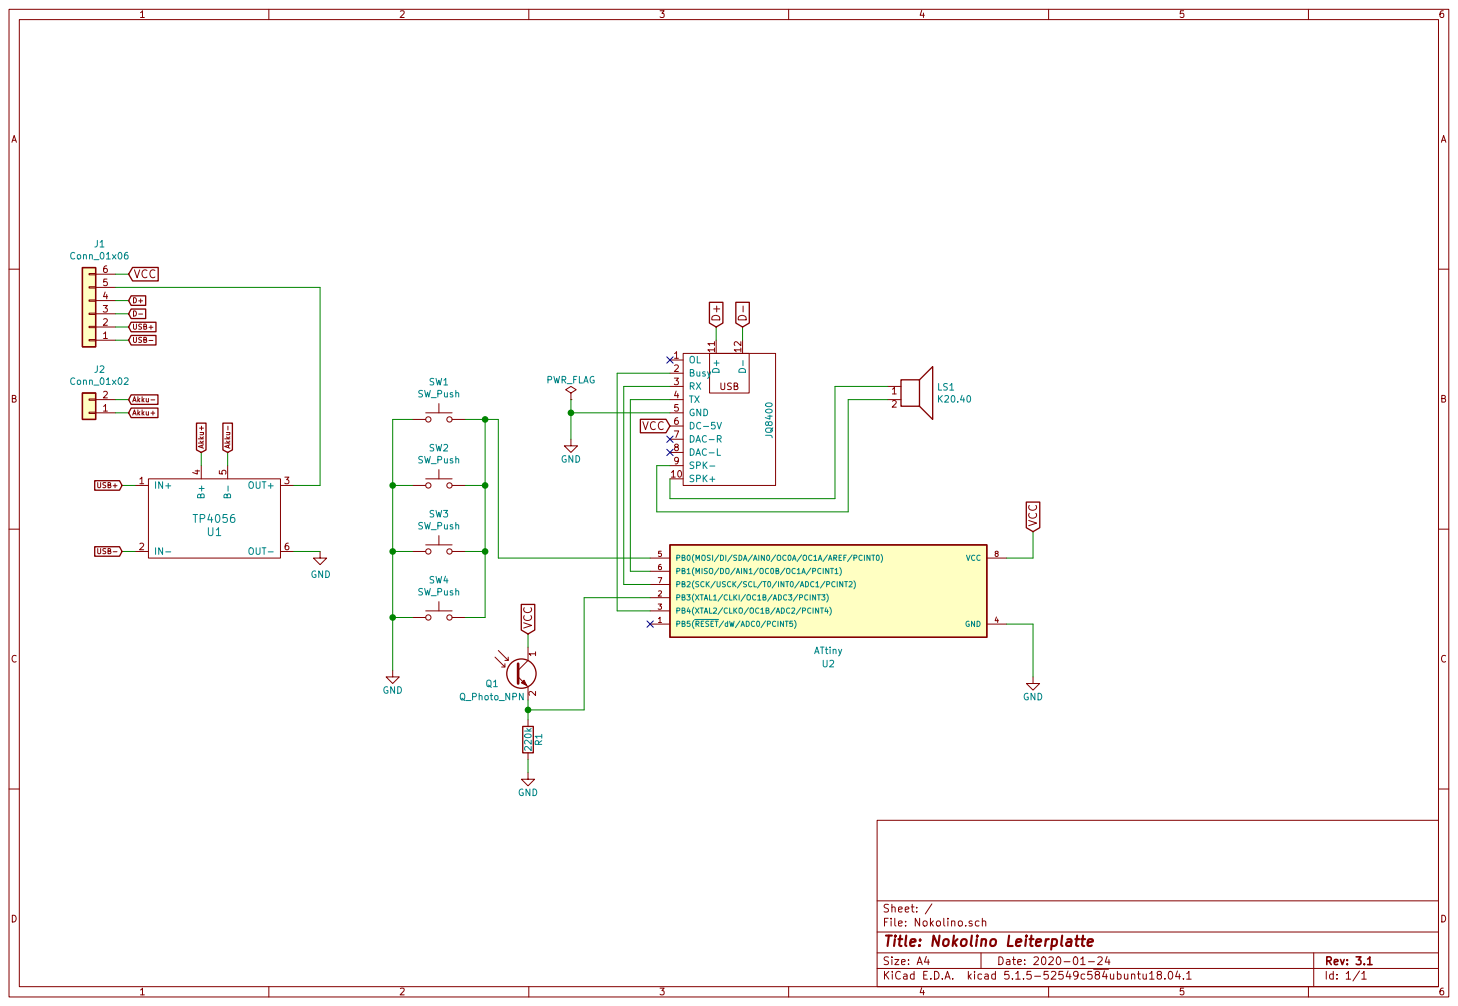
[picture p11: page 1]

1 2 Q1 Q_Photo_NPNGND R1 220k GND GND D- VCC D+ Akku+ Akku- Akku+ VCC

Id: 1/1 Title: Nokolino Leiterplatte

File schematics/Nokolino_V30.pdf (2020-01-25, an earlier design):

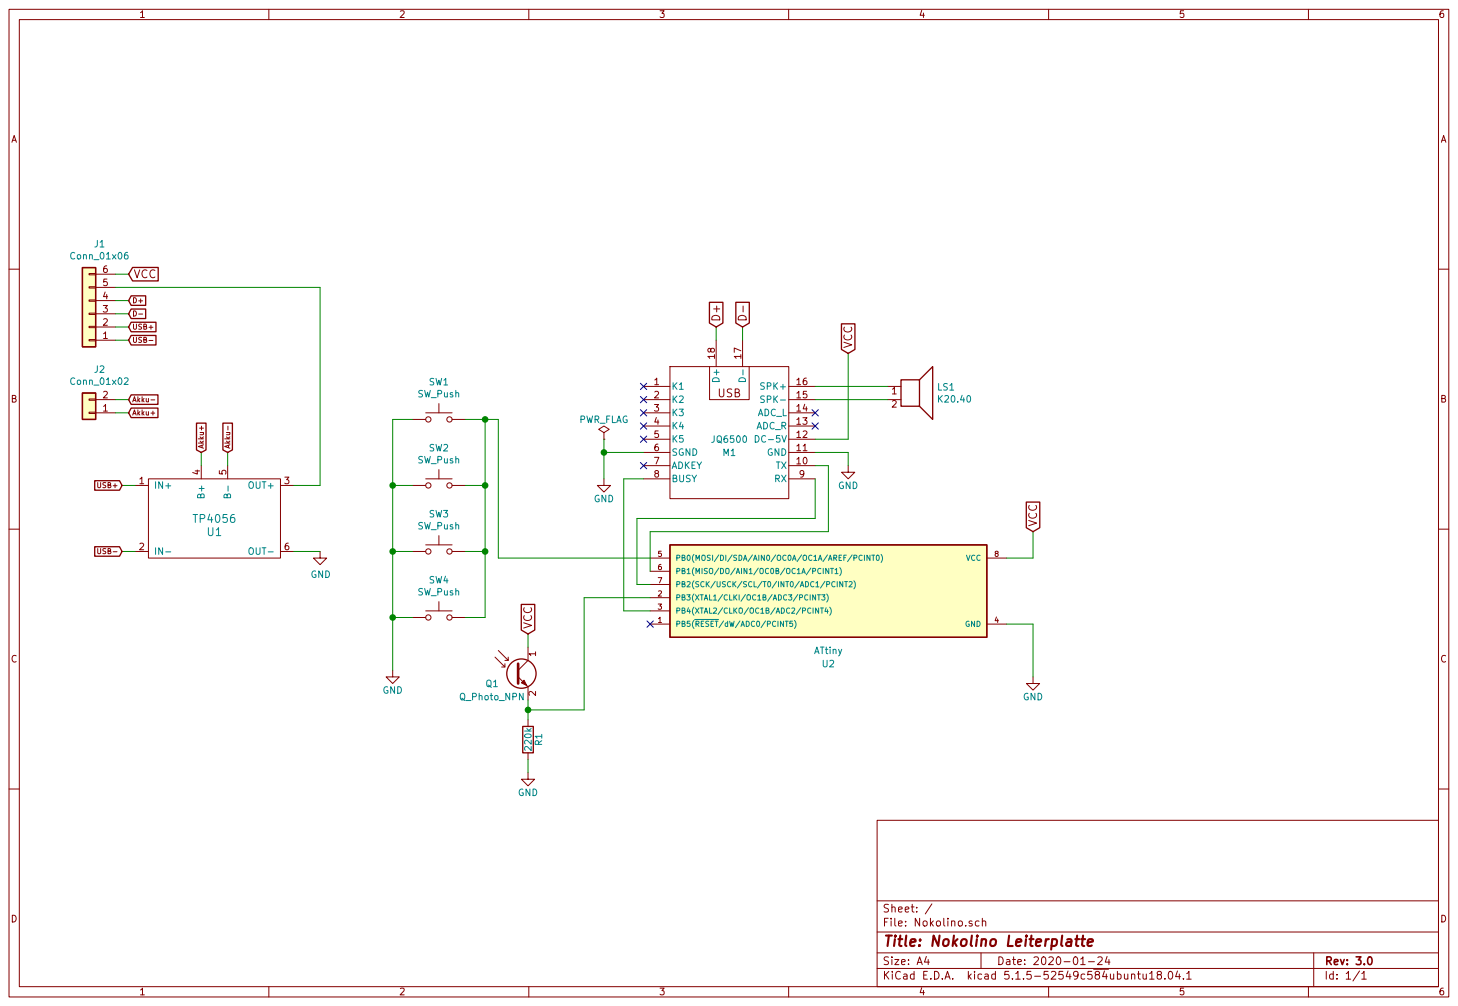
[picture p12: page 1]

Id: 1/1 Title: Nokolino Leiterplatte

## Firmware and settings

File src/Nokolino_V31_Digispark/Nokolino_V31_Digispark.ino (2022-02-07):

/* Nokolino V3.1 25.06.2020 - Nikolai Radke
 *  
 *  Sketch for Mini-Noko-Monster with new JQ8400 module
 *  For ATtiny85 - set to 8 Mhz and remember to flash your bootloader first
 *  
 *  Flash-Usage: 3.972 (IDE 1.8.12 | AVR 1.8.3 | ATtiny 1.0.2 | Linux X86_64 | ATtiny85 )
 *  
 *  Circuit:
 *  1: RST | PB5  free
 *  2: A3  | PB3  Optional SFH300  
 *  3: A2  | PB4  Busy JQ8400 - 2
 *  4: GND |      GND
 *  5: D0  | PB0  Button      - GND
 *  6: D1  | PB1  TX JQ8400   - 4
 *  7: D2  | PB2  RX JQ8400   - 3       
 *  8: VCC        VCC
 *  
 *  Sleepmodes:
 *  0=16ms, 1=32ms, 2=64ms, 3=128ms, 4=250ms, 5=500ms
 *  6=1sec, 7=2sec, 8=4sec, 9=8sec
 */

#include <avr/sleep.h>
#include <avr/interrupt.h>
#include <SoftSerial.h>
#include <EEPROM.h>

//--------------------------------------------------------------------------------
// Configuation
#define Time         10             // Say something every statistical 10 minutes
#define Volume       25             // Volume 0-30 - 25 is recommended 
#define Darkness     4              // Optional: The lower the darker the light must be

#define Button_event 40             // Last button event number (XXX.mp3)
#define Time_event   163            // Last time event number -> Very last file is "beep"

//#define Breadboard                // Breadboard or PCB?
#ifdef Breadboard
  #define Offset       0.3          // Battery measuring error
  #define maxInput     50           // Max. value from busy line 
#else
  #define Offset       0.1
  #define maxInput     0
#endif

// Optional - comment out with // to disable o remove // to enable
#define StartupBeep                 // Will say "beep" when turned on
#define BatteryWarning              // Gives a warning when battery is low
//#define LightSensor               // Will be quite in the dark
//#define SleepComplain             // Will complain if button pressed while its dark

//---------------------------------------------------------------------------------

// Optional battery warning
#define minCurrent   3.30 +Offset   // Low power warning current + measuring error
#define battLow      3.10 +Offset   // Minimal voltage before JQ8400 fails

// Hardware pins
#define TX      1
#define RX      2
#define Busy    2

// ADC and BOD
#ifndef cbi
  #define cbi(sfr, bit) (_SFR_BYTE(sfr) &= ~_BV(bit))
#endif
#ifndef sbi
  #define sbi(sfr, bit) (_SFR_BYTE(sfr) |= _BV(bit))
#endif
#define BODS 7                         // BOD sleep bit in MCUCR
#define BODSE 2                        // BOD sleep enable bit in MCUCR

// Variables
uint16_t seed,files;
uint16_t eeprom=1;
uint16_t *address;
volatile boolean f_wdt = 1;            // Volatile -> it is an interrupt routine
boolean  low=false;
boolean  dark=false;
char     count_files;
uint8_t  files_byte[6];

SoftSerial mp3(TX,RX);                 // TX to D2, RX to D1

int main(void) {
  
init(); {
  // Power saving
  MCUCR |= _BV(BODS) | _BV(BODSE);     // Disable brown out detection - default?
  ACSR |= _BV(ACD);                    // Disable analog comparator - default?
  setup_watchdog(3);                   // Set sleep time to 128ms  

  // Port Setup
  pinMode(0,INPUT);                    // D0 INPUT
  digitalWrite(0,HIGH);                // D0 HIGH

  // Start JQ8400
  newdelay(750);                       // JQ8400 needs a short time to settle
  mp3.begin(9600);
  mp3.write("\xAA\x13\x01");
  mp3.write(Volume);                   // Set volume 0-30
  mp3.write((uint8_t) 190+Volume);     // Calculate and write checksum
  newdelay(100);
  mp3.write("\xAA\x0C");               // Count files on module
  mp3.write((uint8_t) 0x00);
  mp3.write(0xB6);
  newdelay(100);
  for (seed=0;seed<6;seed++)           // Read 6 HEX chars from module
    files_byte[seed]=(uint8_t) mp3.read();// and convert the chars into uint8_t
  files=16*files_byte[3]+files_byte[4];// Convert 2 bytes into uint16_t

  // Nokolino mode | else Music box mode
  if (files==Time_event+1) {
    address=&eeprom;
  // Randomize number generator
  *address=eeprom_read_word(0);         // Read EEPROM address
  if ((*address<2) || (*address>(EEPROM.length()-3))) {
  // Initialize EEPROM and size for first use or after end of cycle
    *address=2 ;                       // Starting address
    eeprom_write_word(0,*address);      // Write starting address
    eeprom_write_word(address,0);      // Write seed 0
  }
  seed=eeprom_read_word(address);     // Read seed
  if (seed>900) {                      // After 900 write-cyles move to another address                                   
    seed=0;                            // to keep the EEPROM alive
    *address+=2;
    eeprom_write_word(0,*address);
  }
  randomSeed(seed);                    // Randomize
  seed++;                              // New seed
  eeprom_write_word(address,seed);     // Save new seed for next startup
    // Optional startup beep
    #ifdef StartupBeep    
      JQ8400_play(Time_event+1);       // Nokolino says "Beep"
      newdelay(1000);                  // Busy is not working well afer startup
    #endif 
  }   
  mp3.write("\xAA\x04");               // Stop and sleep        
  mp3.write((uint8_t) 0x00);           // Needed for Music box mode
  mp3.write(0xAE);                     // and no startup beep
  newdelay(100);
}

// Main loop
while(1) {
  // Wait for button or time and go to sleep - ~8 times/second         
  if (!low) {                          // Quiet if battery too low
    if (!digitalRead(0)) {              // If button is pressed then
      if (dark) {                      // if fototransistor is available
        #ifdef SleepComplain           // and complain feature enabled
          if (files==Time_event+1)     // and not in music box mode
            JQ8400_play(Time_event);   // complain when button pressed
        #endif
      }
      else if (files==Time_event+1) 
        JQ8400_play(random(0,Button_event+1)); // Button event
      else {
        JQ8400_play(eeprom);         // or single music box files 
        (eeprom==files)? eeprom=1:eeprom++;
      }
    }
    else if ((!dark) && (files==Time_event+1) && (random(0,Time*60*8)==1)) // Time event
      JQ8400_play(random(Button_event+1,Time_event+1)); 
  }
  attiny_sleep();                      // Safe battery
  
  // Optional: Check darkness
  #ifdef LightSensor
    if (analogRead(A3)<=Darkness) dark=true;
    else dark=false;
  #endif
}}

void JQ8400_play(uint8_t f) {          // Plays MP3 file
  mp3.write("\xAA\x07\x02");           // Play file number f
  mp3.write((uint8_t) 0x00);
  mp3.write(f);
  mp3.write((uint8_t) 179+f);          // Calculate und wirte checksum
  newdelay(100);
  while (analogRead(2)>maxInput) 
    attiny_sleep();                    // Check busy
  newdelay(100);
 }

void attiny_sleep() {                  // Sleep to save power  
  cbi(ADCSRA,ADEN);                    // Switch ADC off
  set_sleep_mode(SLEEP_MODE_PWR_DOWN); 
  sleep_mode();                                         
  sbi(ADCSRA,ADEN);                    // Switch ADC on
}

void newdelay(uint16_t z)              // New delay function to save flash
{
  uint32_t zmillis=millis();
  while (millis()-zmillis<z);
}

void setup_watchdog(uint8_t mode) {    // Setup wake time
  uint8_t bb;
  bb=mode & 7;
  if (mode > 7) bb|= (1<<5);
  bb|= (1<<WDCE);
  MCUSR &= ~(1<<WDRF);
  WDTCR |= (1<<WDCE) | (1<<WDE);
  WDTCR = bb;
  WDTCR |= _BV(WDIE);
}

ISR(WDT_vect) {                       // Set global flag
  f_wdt=1; 
}

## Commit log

2018-06-29 Improved power saving when battery is low
2018-08-31 Optimized PCB battery warning settings
2018-09-05 New schematics and a new phototransistor feature!
    [NOKOlino.sch, NOKOlino_V11.sch]
2019-04-05 updated mp3 uploader
    [NOKOlino.sch]
2019-04-16 New schematics for upcoming version V3.0
    [NOKOlino-2019-04-13-20-46-27.sch, NOKOlino-2019-04-13-20-49-05.sch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]
2019-04-17 Removed wrong drill map in gerber files
2019-05-12 Reworked new V3 PCB gerber files
2019-08-03 NOKOlino goes into upload mode when button is pressed at startup
2019-12-30 New V3.0 firmware. Hardware PCB will follow soon.
2020-01-01 New V30 PCB files
    [NOKOlino-2019-04-13-20-46-27.sch, NOKOlino-2019-04-13-20-49-05.sch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]
2020-01-02 Updated V30 drill file. Just a cosmetic correction.
    [NOKOlino.kicad_pcb, NOKOlino.sch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]
2020-01-25 New V3.0 PCB design
    [NOKOlino-B_Cu.gbr, NOKOlino-B_Mask.gbr, NOKOlino-B_Paste.gbr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]
2020-02-11 New V31 version für jq8400 modules added.
    [Nokolino-B_Cu.gbr, Nokolino-B_Mask.gbr, Nokolino-B_Paste.gbr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]
2020-02-14 Renewed top PCB design for new 3D printedbutton caps and optional phototransistor
    [Nokolino.kicad_pcb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]
2020-02-14 Added STL file for 3D printed M2 button caps
    [M2_button_cab.stl]
2020-03-09 Slightly updated top PCB
    [Nokolino_top-B_Cu.gbr, Nokolino_top-B_Mask.gbr, Nokolino_top-B_Paste.gbr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]
2020-03-10 Updated V3.1 schematics
    [Nokolino-B_Cu.gbr, Nokolino-B_Mask.gbr, Nokolino-B_Paste.gbr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]
2020-06-12 updated V30 gerber file
2022-01-28 V3.2 now supports all DFPlayers an battery warning
2022-04-28 Fixed errors in comments
    [Nokolino_V32.ino]
2023-03-18 Fixed old battery low flag bug
    [Nokolino_V21.ino, Nokolino_V30.ino, Nokolino_V31.ino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]
